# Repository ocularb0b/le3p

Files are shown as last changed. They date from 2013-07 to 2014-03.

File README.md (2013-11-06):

le3p
====

An H-Gantry RepRap 3d Printer. Designed with Python/FreeCAD

# Overall Design Goals
This is a RepRap printer in so far as it can replicate many of it's parts. It has a low MachineSize to PrintArea ratio. Printable STL's and a BOM is output by a FreeCAD Macro. It's frame is t-slot extrusions and can currently be built with 15mm OpenBeam or 20mm Misumi extrusions. The design is parametric with regard to overall print area.

# Status
I've built this machine as configured by default and it is working.
Mechanics are solid and accurate.
Still working and getting great settings for the extruders.
I'm waiting on a relay that I'll use for the bed heater. Waiting for the bed to heat up has cost me a ton of time.

Not all of the printed parts are properly placed for printing in the STL files.  
So check the orientation before printing anything.
I'm working on cleaning up the code and I'll make some basic instructions for using the script very soon.

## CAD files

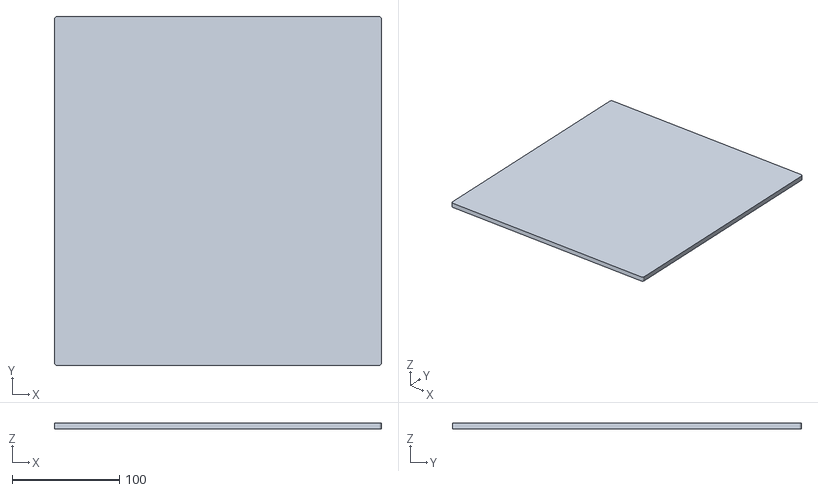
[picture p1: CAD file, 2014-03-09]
stls/bed/export_BedBasePlate.stl
305.0 x 325.5 x 6.00

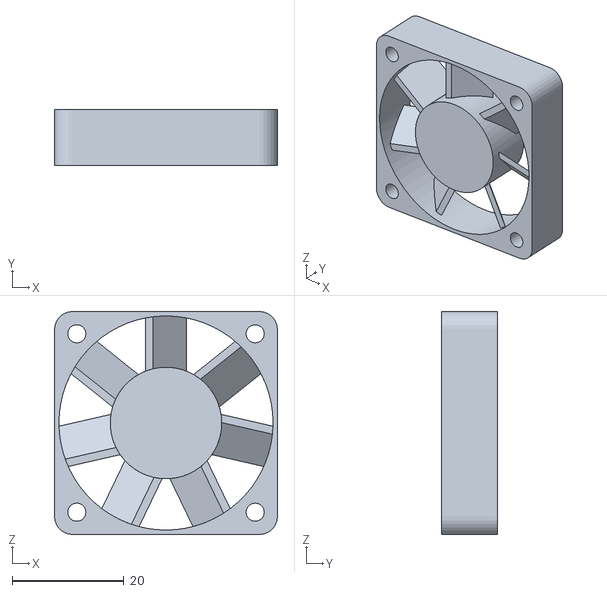
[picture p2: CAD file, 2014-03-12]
stls/electronics/export_HotEndFan.stl
40.0 x 10.0 x 40.0

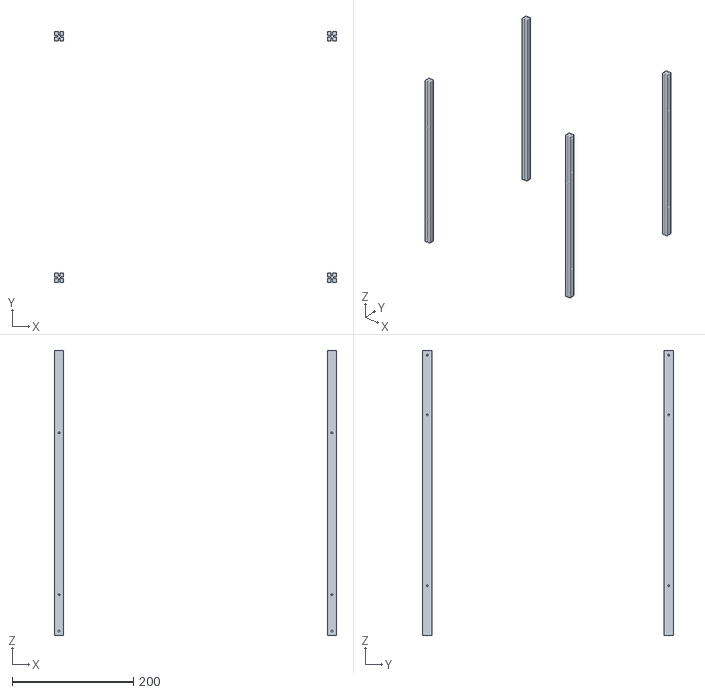
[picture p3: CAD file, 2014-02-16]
stls/frame/export_FrameUprights.stl
466.0 x 414.0 x 471.0

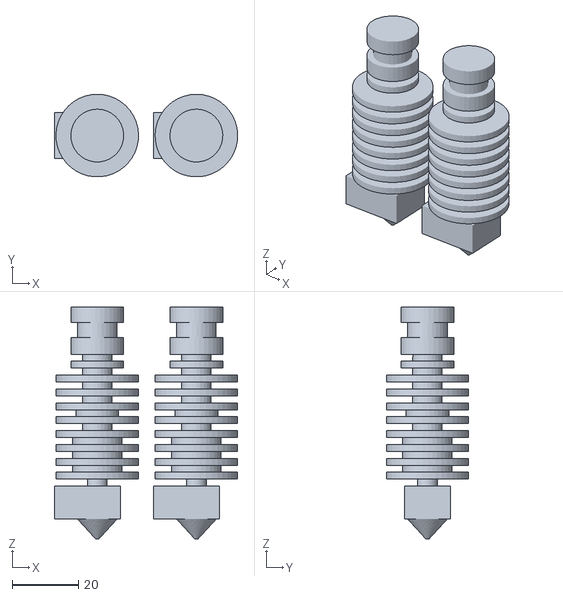
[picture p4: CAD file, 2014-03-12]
stls/manufactured/export_HotEnds.stl
55.5 x 25.0 x 70.2

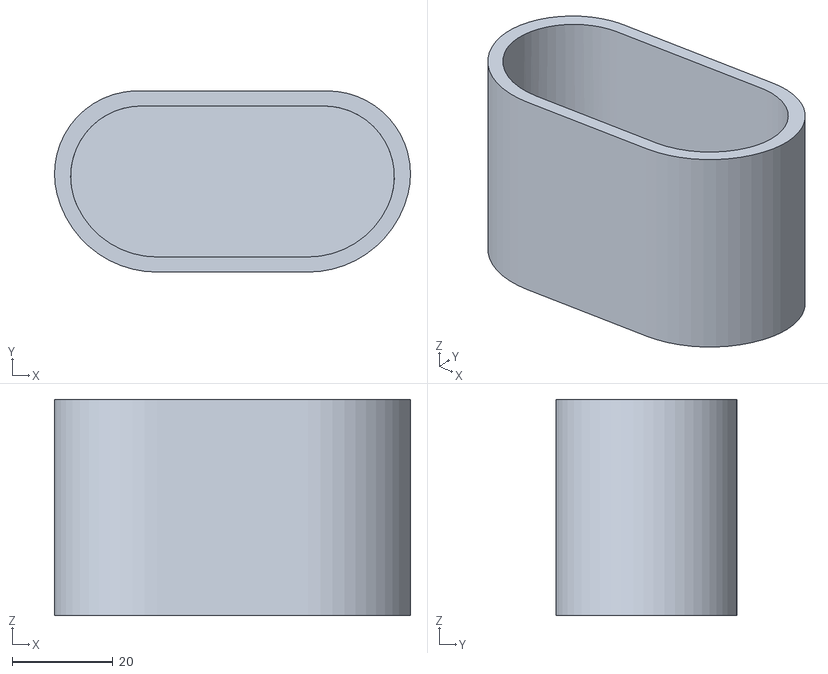
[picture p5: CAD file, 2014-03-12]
stls/printed/forprint_HotEndFanMount.stl
70.7 x 36.0 x 43.0

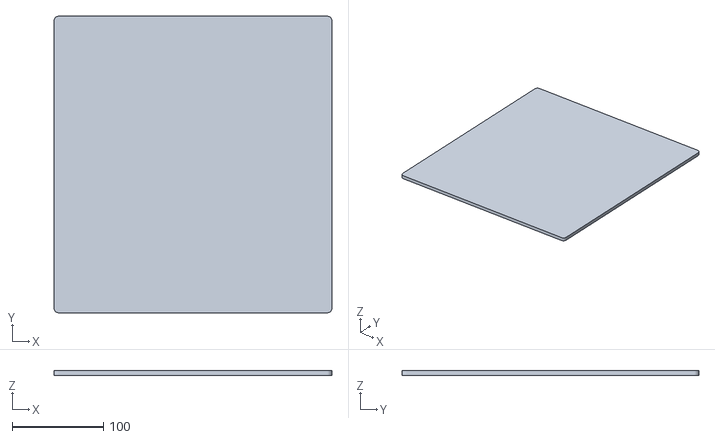
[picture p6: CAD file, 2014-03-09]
stls/bed/export_BedHeatPlate.stl
305.0 x 325.5 x 5.00

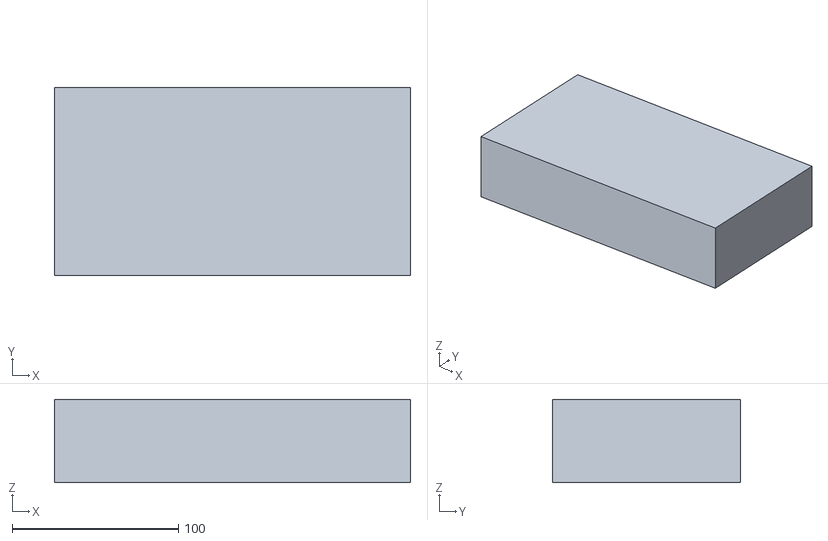
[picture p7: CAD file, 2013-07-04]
stls/electronics/export_PowerSupplyA.stl
214.0 x 113.0 x 50.0

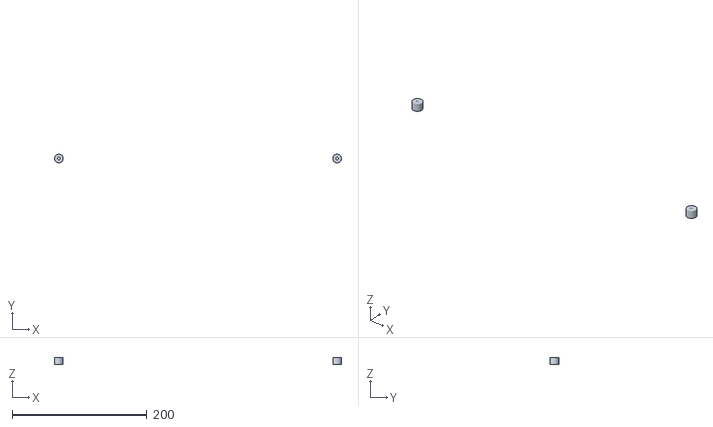
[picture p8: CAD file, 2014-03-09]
stls/manufactured/export_GantryAIdlers.stl
426.0 x 13.0 x 10.0

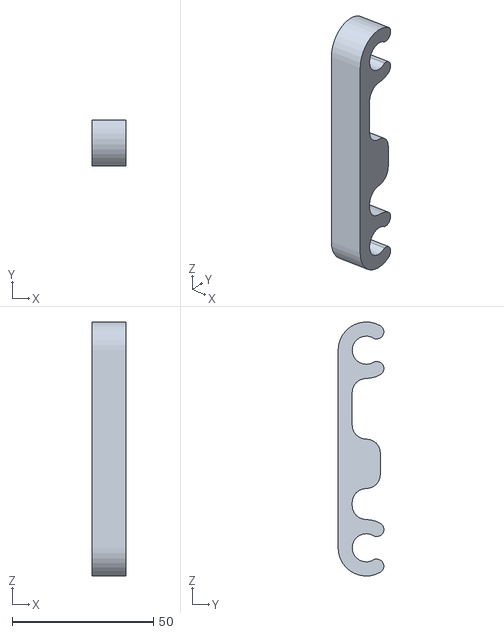
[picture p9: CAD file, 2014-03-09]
stls/printed/export_XStop.stl
12.0 x 16.2 x 90.0

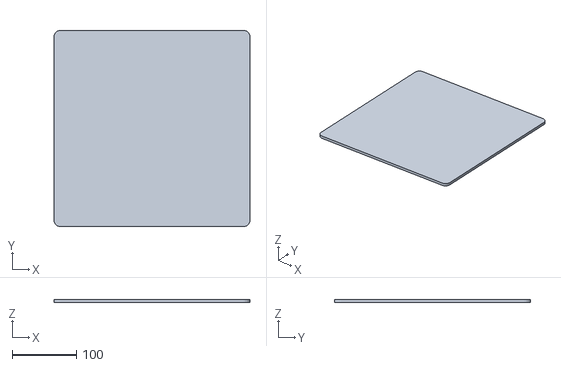
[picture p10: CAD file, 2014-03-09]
stls/bed/export_BedGlassPlate.stl
305.0 x 305.5 x 5.00

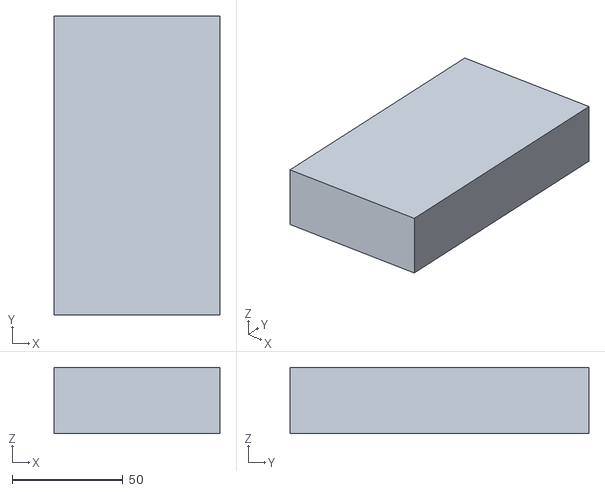
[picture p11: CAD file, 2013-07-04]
stls/electronics/export_ControlBoard.stl
75.0 x 135.0 x 30.0

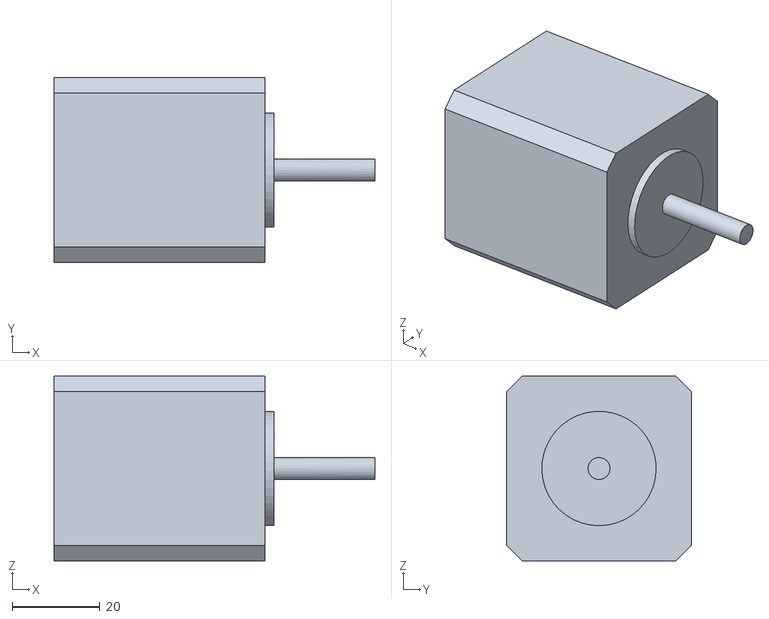
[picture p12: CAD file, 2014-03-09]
stls/manufactured/export_ExtruderMotor.stl
73.0 x 42.0 x 42.0

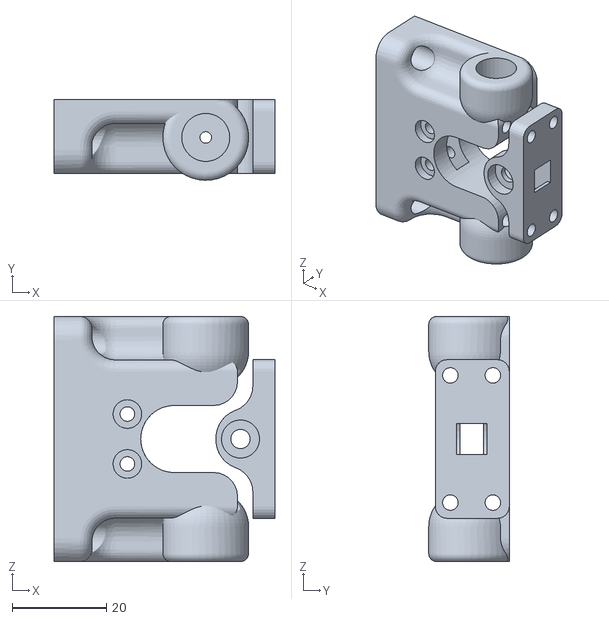
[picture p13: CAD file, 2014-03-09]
stls/printed/export_ExtruderDriver.stl
46.8 x 17.1 x 52.0

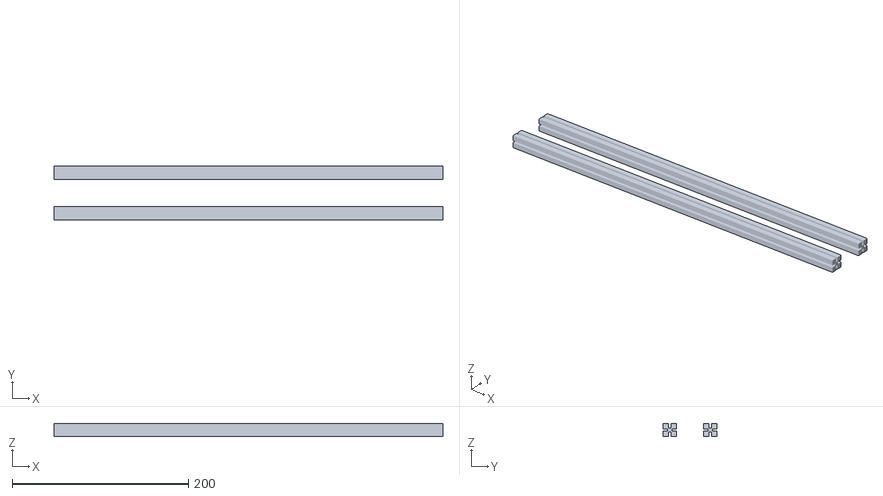
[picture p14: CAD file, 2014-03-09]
stls/bed/export_BedFrame.stl
441.0 x 61.0 x 15.0

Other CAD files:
stls/electronics/export_PowerSupplyB.stl
stls/manufactured/export_GantryCIdlers.stl
stls/printed/forprint_XStop.stl
stls/manufactured/export_GantryBIdlers.stl
stls/manufactured/export_ExtruderDriveGear.stl
stls/manufactured/export_ExtruderIdleBearing.stl
stls/manufactured/export_ExtruderSupportBearing.stl
stls/manufactured/export_GantryBelt.stl
stls/manufactured/export_GantryMotors.stl
stls/manufactured/export_GantryXBushings.stl
stls/manufactured/export_GantryXRods.stl
stls/manufactured/export_GantryYBushings.stl
stls/manufactured/export_GantryYRods.stl
stls/manufactured/export_GantryZBushings.stl
stls/manufactured/export_GantryZLeadNuts.stl
stls/manufactured/export_ZCouplers.stl
stls/manufactured/export_ZMotors.stl
stls/printed/export_ControllerArm.stl
stls/printed/export_DimmerMount.stl
stls/printed/export_GantryMotorMounts.stl
stls/printed/export_LedBracket.stl
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

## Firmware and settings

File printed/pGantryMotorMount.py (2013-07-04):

#le3p-v0.1.3 - pGantryMotorMount.py

# le3p - A larger envelope, t-slot extrusion based, H-Gantry 3D printer.
#
# Copyright (c) 2013 Scott Maher scott.a.maher@gmail.com
#
# This file is part of le3p

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
from __future__ import division
import sys
import FreeCAD, Part, math
from FreeCAD import Vector
from FreeCAD import Matrix

from config import basicConfig
from config import advancedConfig
from config import displayConfig
from config import partSizes

from include.parts import CapHeadScrew

bc = basicConfig.basicConfig()
dc = displayConfig.displayConfig()
ac = advancedConfig.advancedConfig()
ps = partSizes.partSizes()

def gantryMotorMounts():
    xsize = (ac.frameringxlen/2 + ac.beamSize/2) - (ac.gantrymotorxpos - ac.beamSize/2 - ac.gantryMotor[0]/2 - ac.minthick - ps.m3l[1])
    ysize = ac.minthick*2 + ac.gantryMotor[0] + 0.75
    zsize = (ac.frameringczpos + ac.beamSize/2) - (ac.yrodzpos - bc.gantryRodDia/2 - ac.beamSize)
    print 'zsize = {x}'.format(x=zsize)
    #Body Blank
    bb = Part.makeBox(xsize,ysize,zsize)
    bb.translate(Vector(ac.frameringxlen/2 - xsize + ac.beamSize,ac.frameringylen/2 + ac.tailadd/2 + ac.beamSize ,ac.frameringczpos - zsize + ac.beamSize/2))
    bb=bb.makeFillet(ac.minthick,[bb.Edges[1],bb.Edges[2],bb.Edges[3],bb.Edges[5],bb.Edges[6],bb.Edges[7],])
    #Upper Gusset
    ug = Part.makeBox(ac.gantryMotor[0]*2,ac.gantryMotor[0]*2,ac.gantryMotor[0]*2)
    ug.translate(Vector(ac.gantrymotorxpos-ac.gantryMotor[0],ac.gantrymotorypos+ac.gantryMotor[0]/2-ac.gantryMotor[0],ac.gantrymotorzpos+ac.minthick*2))
    ug=ug.makeFillet(ac.gantryMotor[0],[ug.Edges[8]])
    #Lower Gusset
    lg = Part.makeCylinder(ac.gantryMotor[0],ac.gantryMotor[0]*2)
    lg.translate(Vector(0,0,-ac.gantryMotor[0]))
    lg.rotate(Vector(0,0,0),Vector(0,1,0),90)
    lg.translate(Vector(ac.gantrymotorxpos,ac.gantrymotorypos+ac.gantryMotor[0]/2,ac.gantrymotorzpos-ac.gantryMotor[0]))
    
    #Motor Cut
    tol = 1
    mc = Part.makeBox(ac.gantryMotor[0]+tol,ac.gantryMotor[0]+tol,ac.gantryMotor[1])
    mc.translate(Vector(ac.gantrymotorxpos-ac.gantryMotor[0]/2-tol/2,ac.gantrymotorypos-ac.gantryMotor[0]/2-tol/2,ac.gantrymotorzpos-ac.gantryMotor[1]))
    #Idle Cut
    ic = Part.makeBox(ac.gantryMotor[0],ac.gantryMotor[0],ac.gantryMotor[1]*2)
    ic.translate(Vector(ac.gantrymotorxpos-ac.gantryMotor[0]/2,ac.gantrymotorypos-ac.gantryMotor[0]/2,ac.gantrymotorzpos+ac.minthick*2))
    ic = ic.makeFillet(ac.gantryMotor[0]/2 - 0.01,[ic.Edges[0],ic.Edges[4]])
    #Motor Face Cut
    mfc = Part.makeCylinder(ac.gantryMotor[5]/2+ac.minthick/2,ac.minthick*2)
    mfc.translate(Vector(ac.gantrymotorxpos,ac.gantrymotorypos,ac.gantrymotorzpos))
    #Motor Mount Screws
    mms = CapHeadScrew(l=10,d=ps.m3l[0],hd=ps.m3l[1],hh=ps.m3l[2],cut=1)
    mms.translate(Vector(ac.gantryMotor[4]/2,ac.gantryMotor[4]/2,ac.gantrymotorzpos + ac.minthick*2 - ps.m3l[2]))
    mms = mms.fuse(mms.mirror(Vector(0,0,0),Vector(1,0,0)))
    mms = mms.fuse(mms.mirror(Vector(0,0,0),Vector(0,1,0)))
    mms.translate(Vector(ac.gantrymotorxpos,ac.gantrymotorypos,0))
    #Mount Screws
    ms1 = CapHeadScrew(l=8,d=ps.m3l[0],hd=ps.m3l[1],hh=ps.m3l[2],cut=1)
    ms1.rotate(Vector(0,0,0),Vector(1,0,0),-90)
    ms1.translate(Vector(ac.frameringxlen/2+ac.beamSize/2,ac.frameringylen/2+ac.beamSize+ac.tailadd/2+ac.minthick*2-ps.m3l[2],ac.frameringczpos))
    ms2 = CapHeadScrew(l=8,d=ps.m3l[0],hd=ps.m3l[1],hh=ps.m3l[2],cut=1)
    ms2.rotate(Vector(0,0,0),Vector(1,0,0),-90)
    ms2.translate(Vector(ac.frameringxlen/2+ac.beamSize*1.5-xsize,ac.frameringylen/2+ac.beamSize+ac.tailadd/2+ac.minthick*2-ps.m3l[2],ac.frameringczpos))
    ms3 = CapHeadScrew(l=8,d=ps.m3l[0],hd=ps.m3l[1],hh=ps.m3l[2],cut=1)
    ms3.rotate(Vector(0,0,0),Vector(1,0,0),-90)
    ms3.translate(Vector(ac.frameringxlen/2-ac.beamSize/2,ac.frameringylen/2+ac.beamSize+ac.tailadd/2+ac.minthick*2-ps.m3l[2],ac.frameringczpos))
    ms4 = CapHeadScrew(l=8,d=ps.m3l[0],hd=ps.m3l[1],hh=ps.m3l[2],cut=1)
    ms4.rotate(Vector(0,0,0),Vector(1,0,0),-90)
    ms4.translate(Vector(ac.frameringxlen/2+ac.beamSize/2,ac.frameringylen/2+ac.beamSize+ac.tailadd/2+ac.minthick*2-ps.m3l[2],ac.yrodzpos-bc.gantryRodDia/2-ac.beamSize/2))
    ms5 = CapHeadScrew(l=8,d=ps.m3l[0],hd=ps.m3l[1],hh=ps.m3l[2],cut=1)
    ms5.rotate(Vector(0,0,0),Vector(1,0,0),-90)
    ms5.translate(Vector(ac.frameringxlen/2+ac.beamSize*1.5-xsize,ac.frameringylen/2+ac.beamSize+ac.tailadd/2+ac.minthick*2-ps.m3l[2],ac.yrodzpos-bc.gantryRodDia/2-ac.beamSize/2))
    ms6 = CapHeadScrew(l=8,d=ps.m3l[0],hd=ps.m3l[1],hh=ps.m3l[2],cut=1)
    ms6.rotate(Vector(0,0,0),Vector(1,0,0),-90)
    ms6.translate(Vector(ac.frameringxlen/2-ac.beamSize/2,ac.frameringylen/2+ac.beamSize+ac.tailadd/2+ac.minthick*2-ps.m3l[2],ac.yrodzpos-bc.gantryRodDia/2-ac.beamSize/2))
    ms7 = CapHeadScrew(l=8,d=ps.m3l[0],hd=ps.m3l[1],hh=ps.m3l[2],cut=1)
    ms7.rotate(Vector(0,0,0),Vector(1,0,0),-90)
    ms7.translate(Vector(ac.frameringxlen/2+ac.beamSize/2,ac.frameringylen/2+ac.beamSize+ac.tailadd/2+ac.minthick*2-ps.m3l[2],((ac.frameringczpos)+(ac.yrodzpos-bc.gantryRodDia/2-ac.beamSize/2))/2))
    #belt paths
    bpx = ac.beltThick+ac.beltSpace
    bpy = ac.minthick*4
    bpz = ac.beltThick+ac.beltSpace*2
    bp = Part.makeBox(bpx,bpy,bpz)
    bp = bp.makeFillet(ac.beltThick/2,[bp.Edges[1],bp.Edges[3],bp.Edges[5],bp.Edges[7]])
    bpa = bp.copy()
    bpb = bp.copy()
    bpa.translate(Vector(ac.gantrymotorxpos+ps.z624[1]/2+ac.beltThick/2-bpx/2,ac.frameringylen/2+ac.tailadd/2+ac.beamSize/2+ac.minthick,ac.gantrydrivecenter-bpz/2))
    bpb.translate(Vector(ac.gantrymotorxpos-ps.z624[1]/2-ac.beltThick/2-bpx/2,ac.frameringylen/2+ac.tailadd/2+ac.beamSize/2+ac.minthick,ac.gantrydrivecenter-bpz/2))
    
    mss=ms1.fuse(ms2.fuse(ms3.fuse(ms4.fuse(ms5.fuse(ms6.fuse(ms7))))))
    
    gmm = bb.cut(ug)
    gmm = gmm.cut(lg)
    gmm = gmm.cut(mc.fuse(ic))
    gmm = gmm.cut(mfc)
    gmm = gmm.cut(mms)
    gmm = gmm.cut(mss)
    gmm = gmm.cut(bpa.fuse(bpb))
    
    #stupid fix
    gmm = gmm.mirror(Vector(0,0,0),Vector(1,0,0))
    
    if dc.noMirror == 0:
    	gmm = gmm.fuse(gmm.mirror(Vector(0,0,0),Vector(1,0,0)))
    return gmm

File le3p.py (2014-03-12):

#le3p v0.1.3

# le3p - A larger envelope, t-slot extrusion based, H-Gantry 3D printer.
#
# Copyright (c) 2013 Scott Maher scott.a.maher@gmail.com
#
# This file is part of le3p

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
from __future__ import division
import sys
import FreeCAD, Part, math
from FreeCAD import Vector
from FreeCAD import Matrix

from include.parts import E3Dv4
from include.parts import Kraken
from include.parts import BoxExtrusion
from include.parts import CapHeadScrew
from include.parts import NemaMotor
from include.parts import TimingGear
from include.parts import StraightBushing
from include.parts import Bearing
from include.parts import Fan
from include.shapes import regPolygon
from include.shapes import BeltCorner
from include.shapes import TSlot
from include.shapes import RodClampSlice
from include.shapes import FilletFlange

test = FreeCAD.activeDocument()
if test == None:
	clear = 0
else:
	clear = 1

from config import basicConfig
from config import advancedConfig
from config import displayConfig
from config import partSizes

from assemblies import aBed 

from printed import pXCarriage
from printed import pXEnds
from printed import pYEnds
from printed import pZEnds
from printed import pGantryMotorMount
from printed import pZMotorMount
from printed import pBits
from printed import pZCarriage
from printed import pToolHolder
from printed import pExtruderDriverDirectPG35
from printed import pExtruderDriverDirectNEMA17
from printed import pCornerBracket

if clear == 1:
	reload(basicConfig)
	reload(displayConfig)
	reload(advancedConfig)
	reload(partSizes)
	reload(aBed)
	reload(pXCarriage)
	reload(pXEnds)
	reload(pYEnds)
	reload(pZEnds)
	reload(pGantryMotorMount)
	reload(pZMotorMount)
	reload(pZCarriage)
	reload(pToolHolder)
	reload(pExtruderDriverDirectPG35)
	reload(pExtruderDriverDirectNEMA17)
	reload(pBits)
	reload(pCornerBracket)

bc = basicConfig.basicConfig()
dc = displayConfig.displayConfig()
ac = advancedConfig.advancedConfig()
ps = partSizes.partSizes()

# Preprocess
if dc.forPrint == 1:
	dc.showBedSurface = 0
	dc.showElectronics = 0
	dc.showFrame = 0
	dc.showManufacturedParts = 0
	dc.showExtruderParts = 0


# Layout Functions ###################################################################################################

# Manufactured Parts
def HotEndsLayout():
	if bc.hotEndType == 'DualE3Dv4':
		t1 = E3Dv4()
		t1.rotate(Vector(0,0,0),Vector(0,0,1),90)
		t1.translate(Vector(-ac.hotEndDia/2 - ac.hotEndSpacing/2,0, ac.hotEndLen))
		t1.translate(Vector(ac.mXpos, ac.mYpos, ac.envelopeZ))
	
		t2 = E3Dv4()
		t2.rotate(Vector(0,0,0),Vector(0,0,1),90)
		t2.translate(Vector(ac.hotEndDia/2 + ac.hotEndSpacing/2,0, ac.hotEndLen))
		t2.translate(Vector(ac.mXpos, ac.mYpos, ac.envelopeZ))
			
		f1 = t1.fuse(t2)
		ts=f1		
		return ts
	if bc.hotEndType == 'Kraken':
		t = Kraken()
		t.rotate(Vector(0,0,0),Vector(0,0,1),180)
		t.translate(Vector(ac.mXpos, ac.mYpos, ac.envelopeZ - 65))
		return t
	

def HotEndFanLayout():
	sz=40
	th=10
	dfromnoz=3
	fn = Fan(size=sz,thick=th)
	fn.translate(Vector(-ac.hotEndDia/2 - ac.hotEndSpacing/2,0, ac.hotEndLen-ac.hotEndMountLen-2.4))
	fn.translate(Vector(ac.mXpos-sz/2+ac.hotEndDia/2+ac.hotEndSpacing/2, ac.mYpos-th-ac.hotEndDia/2-dfromnoz, ac.envelopeZ-sz+2.5))

	fan = fn		
	return fan

def NozzleFanLayout():
	sz=30
	th=10
	fn = Fan(size=sz,thick=th)
	fn.rotate(Vector(0,0,0),Vector(1,0,0),0)
	fn.translate(Vector(-ac.hotEndDia/2 - ac.hotEndSpacing/2,0, ac.hotEndLen-ac.hotEndMountLen-2.4))
	fn.translate(Vector(ac.mXpos-sz/2+ac.hotEndDia/2+ac.hotEndSpacing/2, ac.mYpos-th-ac.hotEndDia/2+sz*2, ac.envelopeZ-sz*1.5))

	fan = fn		
	return fan
		
# Gantry
def XRodsLayout():
	xr=Part.makeCylinder(bc.gantryRodDia/2,ac.xrodlen)
	xr.rotate(Vector(0,0,0),Vector(0,1,0),90)
	xr.translate(Vector(-ac.xrodlen/2,ac.xrodypos,ac.xrodzcenter+ac.xrodspacing/2))
	xr2=xr.copy()
	xr2.translate(Vector(0,0,-ac.xrodspacing))
	xr=xr.fuse(xr2)
	xr.translate(Vector(0,ac.mYpos,0))
	return xr
	
def XBushingsLayout():
	xb=StraightBushing(ac.xBushing)
	xb.rotate(Vector(0,0,0),Vector(0,1,0),90)
	xb.translate(Vector(-ac.xBushing[2]/2,ac.xrodypos,ac.xrodzcenter+ac.xrodspacing/2))
	xb.translate(Vector(ac.mXpos,ac.mYpos,0))
	xb2=xb.copy()
	xb2.translate(Vector(0,0,-ac.xrodspacing))
	xb=xb.fuse(xb2)
	return xb
	
def YRodsLayout():
	yr=Part.makeCylinder(bc.gantryRodDia/2,ac.yrodlen)
	yr.rotate(Vector(0,0,0),Vector(1,0,0),-90)
	yr.translate(Vector(ac.yrodxpos,-ac.yrodlen/2 + ac.tailadd/2,ac.yrodzpos))
	yr=yr.fuse(yr.mirror(Vector(0,0,0),Vector(1,0,0)))
	return yr
	
def YBushingsLayout():
	yb=StraightBushing(ac.yBushing)
	yb.rotate(Vector(0,0,0),Vector(1,0,0),-90)
	yb.translate(Vector(ac.yrodxpos,ac.ybushingypos-ac.yBushing[2]/2,ac.yrodzpos))
	yb=yb.fuse(yb.mirror(Vector(0,0,0),Vector(1,0,0)))
	yb.translate(Vector(0,ac.mYpos,0))
	return yb
	
def GantryMotorsLayout():
	gm = NemaMotor(ac.gantryMotor)
	gm.translate(Vector(ac.gantrymotorxpos,ac.gantrymotorypos,ac.gantrymotorzpos))
	gm=gm.fuse(gm.mirror(Vector(0,0,0),Vector(1,0,0)))
	return gm
	
def GantryAIdlersLayout():
	ai = Bearing(ps.z624)
	ai.translate(Vector(ac.gantryaidlerxpos,ac.gantryaidlerypos,ac.gantrydrivecenter))
	ai2=ai.copy()
	ai2.translate(Vector(0,0,-ps.z624[2]))
	ai=ai.fuse(ai2)
	ai=ai.fuse(ai.mirror(Vector(0,0,0),Vector(1,0,0)))
	return ai
	
def GantryBIdlersLayout():
	bi = Bearing(ps.z624)
	bi.translate(Vector(ac.gantrybidlerxpos,ac.gantrybidlerypos,ac.gantrydrivecenter))
	bi2=bi.copy()
	bi2.translate(Vector(0,0,-ps.z624[2]))
	bi=bi.fuse(bi2)
	bi=bi.fuse(bi.mirror(Vector(0,0,0),Vector(1,0,0)))
	bi.translate(Vector(0,ac.mYpos,0))
	return bi
	
def GantryCIdlersLayout():
	ci = Bearing(ps.z624)
	ci.translate(Vector(ac.gantrycidlerxpos,ac.gantrycidlerypos,ac.gantrydrivecenter))
	ci2=ci.copy()
	ci2.translate(Vector(0,0,-ps.z624[2]))
	ci=ci.fuse(ci2)
	ci=ci.fuse(ci.mirror(Vector(0,0,0),Vector(1,0,0)))
	ci.translate(Vector(0,ac.mYpos,0))
	return ci
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

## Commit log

2013-07-04 added stl's
    [export_BedBasePlate.stl, export_BedFrame.stl, export_BedGlassPlate.stl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]
2013-07-07 added pbits.LedBracket()
2013-09-15 cleaned up a bit and added a fan model
    [export_ExtruderDriveGear.stl, export_ExtruderDriver.stl, export_ExtruderIdleBearing.stl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]
2013-10-18 New XCarriage with fan and extruder driver mounts. Framed out for bowden or direct drive setups
    [export_GantryAIdlers.stl, export_GantryBIdlers.stl, export_GantryBelt.stl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]
2013-10-20 LED Dimmer Bracket added
    [export_ControllerArm.stl, export_DimmerMount.stl, export_ExtruderDriveGear.stl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]
2013-11-01 prep for a new xcarriage-struder
    [forprint_NozzleFanShroud.stl]
2013-11-06 some fixes to forPrint positions
    [forprint_YEndsMotor.stl]
2013-11-10 added rear cable conduit. Removed some useless parts.
    [forprint_HotEndFanMount.stl, forprint_RumbaMount.stl]
2014-02-16 added kraken, 10mm bronze bushing and 10mm sleve bushing. began work on Ultimaker/Tantilus style gantry option
    [export_BedFrame.stl, export_FrameUprights.stl, export_GantryXRods.stl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]
2014-03-09 ... added dial test indicator bracket
    [export_BedBasePlate.stl, export_BedFrame.stl, export_BedGlassPlate.stl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]
2014-03-12 started new heat junction fan shroud
    [export_HotEndFan.stl, export_HotEnds.stl, forprint_HotEndFanMount.stl]

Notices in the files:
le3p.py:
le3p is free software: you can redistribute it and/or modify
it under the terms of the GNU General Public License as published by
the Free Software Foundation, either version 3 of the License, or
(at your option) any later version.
